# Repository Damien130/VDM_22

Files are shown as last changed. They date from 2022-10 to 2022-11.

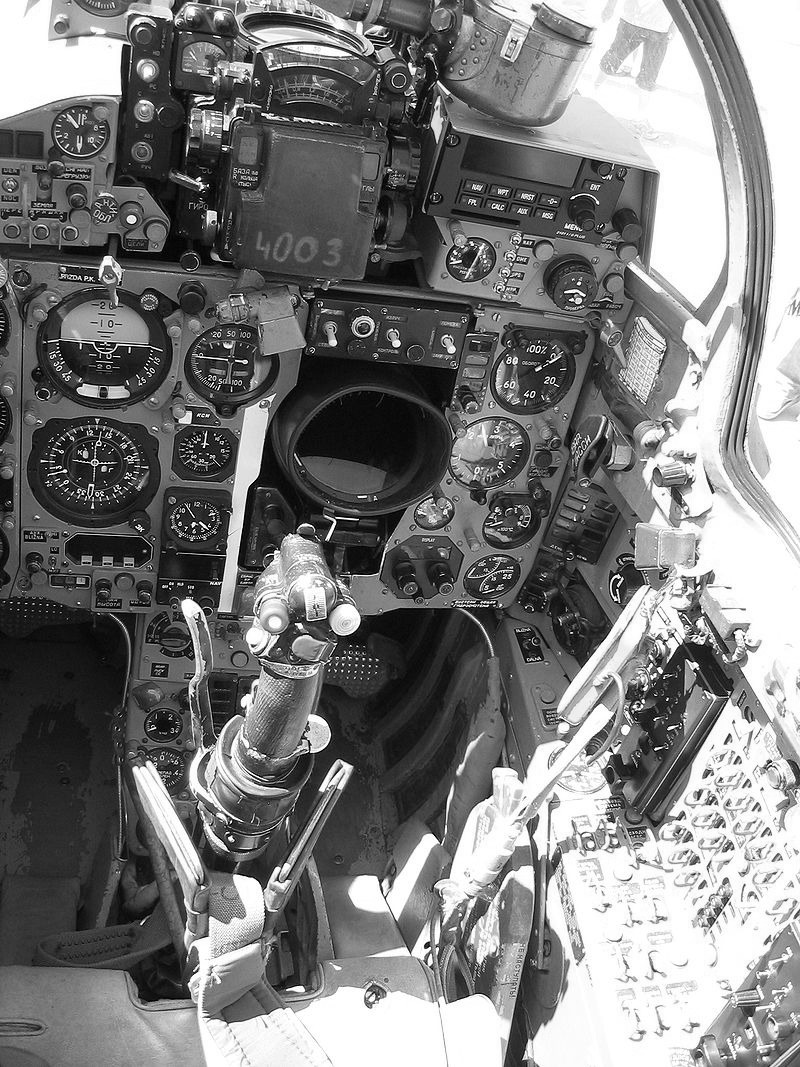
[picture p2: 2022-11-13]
Enclosure Design/image.jpg

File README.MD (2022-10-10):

привет товарищ!

Welcome to your Mikoyan-Gurevich 21, the Pencil.
This will be your jet, you will fly out with Vladimir tomorrow.

What is VDM-22?
The VDM-22 (Vector Drawing Machine - 22) is a vector drawing machine based on the ATMega328P microcontroller. The default machine functions replicates the RP-22 Sapfir radar found on the MiG-21 interceptors. 

Real World Operation
The RP-21/22 Sapfir was an analog radar system developed by the Soviet Union. Used primarily by the MiG-21 Bis, it can detect a fighter sized object from 20 km away flying at the same altitude. The radar antenna scans in a circular motion and emits a characteristic three tone signature on NATO RWRs, earning it the NATO nickname “Spin Scan”. It is capable of operating in three modes – Scan Mode, Chase Mode (locked on) and Fixed Beam (for guiding beam-riding ground attack rockets). 

The interface between the RP-22 and the pilot comes in the form of a circular CRT situated to the lower right side of the MiG-21’s cockpit. The following pictures will depict the two air-to-air operation mode of the radar 

In B-Scope mode, the two horizontal line represents the “lock piper”. When the lock piper is over the bogey (the bird) and the TDC lock button is depressed, the RP-22 will scan the airspace designated by the piper at a high frequency and lock onto any target it sees. 
When used alongside the SRZO-2 IFF interrogator/transponder, the RP-22 is capable of rudimentary IFF operation. When the IFF button is depressed on the radar control panel, the bird will turn into two parallel horizontal lines if the target is friendly and a single line if the target is hostile/unknown. 

When the target is locked following the correct procedure, the RP-22 will enter the “chase mode”. Now instead of a top-down view (a B-scope), the Sapfir will display the C-Scope. The C-Scope displays the azimuth and deviation of the bogey from the centerline of our aircraft, with the two lines on the side representing the distance to target.

When the target is in range for the R3R SARH missile, a red lamp will illuminate with the wording “IN RANGE”. When the target is range, another red lamp “launch” will be lit, giving the pilot launch authorization when he/she presses the missile launch button. 

Gameplay
The gameplay will follow the perspective of a MiG-21/J-7 pilot at the end of GCI guidance. Upon game start, a bogey will appear on the very top edge of the scope (around 30 km). The initial delta V of the two aircrafts will be 800 kts (1481.6kph), which means the player will have about 40 seconds to maneuver the aircraft to lock up the bogey at 15 km. The player will now have to flip on a row of switches – Left Rack Power, Right Rack Power, Left Rack Launch Authorization and Right Rack Launch Authorization to prepare for the engagement. 

Once the player obtains a lock, the interface will be switched to the C-Scope. The bogey has a random chance to start maneuvering and / or lock onto the player’s aircraft. The bogey’s radar status will be reflected by the MiG’s helpful soviet RWR. The RWR, following its real-life model, will consist of one sound unit and 4 LEDS representing the radar emission aspect to own aircraft. When the bogey’s radar is scanning the player’s aircraft, the RWR will beep with the LED flashing in the direction the bogey is coming from. If the bogey obtains a lock / launches a missile, the LED will turn solid, and the beep will turn into a continuous tone/very high frequency beep.  If the bogey obtains a lock on the player, the player must hit the countermeasure dispense button to deploy chaff. For gameplay’s sake, the chaff deployed will have a 100% possibility of confusing the bogey’s targeting system thus ensuring the player’s survival. 

Now if the player manages to evade the bogey’s missile and comes within launch distance (around 7km with both IN RANGE and LAUNCH lamps lit), the player will launch the R3R missile by pressing the missile launch button. If the player launches the missile before the distance closes within 2km, the bogey will be counted as shot down; otherwise, the player will be splashed by a capitalist AIM-9 sidewinder missile. 

Upon finishing one game, the player will press the countermeasures dispense button to start the next round. The next round will multiply the delta V of the player’s aircraft and the bogey’s aircraft by 1.05, and the game will terminate to display score information on the vector scope when delta V reaches 1500 knots.

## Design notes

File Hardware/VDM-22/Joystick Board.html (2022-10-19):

Altium customize

# Board Information Report

Date: | | 10/19/2022
Time: | | 4:58:49 PM
Elapsed Time: | | 00:00:00
Filename: | | Q:\BOP_F14\Hardware\VDM-22\Joystick Board.PcbDoc
Units: | | mmmils

## Contents

Contents

Board Specification

General

Routing

Routing Information

Other

Net Via Size

## Board Specification

General
Board Size | 69mm x 52mm
Components on board | 7

Back to top

## Routing

Routing Information
Routing completion | 100.00%
Connections | -9
Connections routed | -9
Connections remaining | 0

Back to top

## Other

Net Via Size | Count
1.27mm | 39
Total | 39

Back to top

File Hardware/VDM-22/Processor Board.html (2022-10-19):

Altium customize

# Board Information Report

Date: | | 10/19/2022
Time: | | 5:01:15 PM
Elapsed Time: | | 00:00:00
Filename: | | Q:\BOP_F14\Hardware\VDM-22\Processor Board.PcbDoc
Units: | | mmmils

## Contents

Contents

Board Specification

General

Routing

Routing Information

Other

Net Via Size

## Board Specification

General
Board Size | 69.723mm x 95.885mm
Components on board | 48

Back to top

## Routing

Routing Information
Routing completion | 100.00%
Connections | 141
Connections routed | 141
Connections remaining | 0

Back to top

## Other

Net Via Size | Count
1mm | 39
Total | 39

Back to top

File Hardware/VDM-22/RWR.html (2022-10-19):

Altium customize

# Board Information Report

Date: | | 10/19/2022
Time: | | 5:00:46 PM
Elapsed Time: | | 00:00:00
Filename: | | Q:\BOP_F14\Hardware\VDM-22\RWR.PcbDoc
Units: | | mmmils

## Contents

Contents

Board Specification

General

Routing

Routing Information

Other

Net Via Size

## Board Specification

General
Board Size | 29mm x 30mm
Components on board | 9

Back to top

## Routing

Routing Information
Routing completion | 100.00%
Connections | -26
Connections routed | -26
Connections remaining | 0

Back to top

## Other

Net Via Size | Count
1.27mm | 45
Total | 45

Back to top

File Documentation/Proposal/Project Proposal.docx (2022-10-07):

# VDM-22 Sapfir

An RP-22 Sapir Radar Scope implementation for the ATmega 328P

# Overview of Vector Drawing Machine - 22

## Real World Operation

The RP-21/22 Sapfir was an analog radar system developed by the Soviet Union. Used primarily by the MiG-21 Bis, it can detect a fighter sized object from 20 km away flying at the same altitude. The radar antenna scans in a circular motion and emits a characteristic three tone signature on NATO RWRs, earning it the NATO nickname “Spin Scan”. It is capable of operating in three modes – Scan Mode, Chase Mode (locked on) and Fixed Beam (for guiding beam-riding ground attack rockets).

The interface between the RP-22 and the pilot comes in the form of a circular CRT situated to the lower right side of the MiG-21’s cockpit. The following pictures will depict the two air-to-air operation mode of the radar (Fixed Beam for Kh22 is for ground attack only, and will not be implemented in the current iteration):

1. B-Scope (Detection). 2. Chase Mode

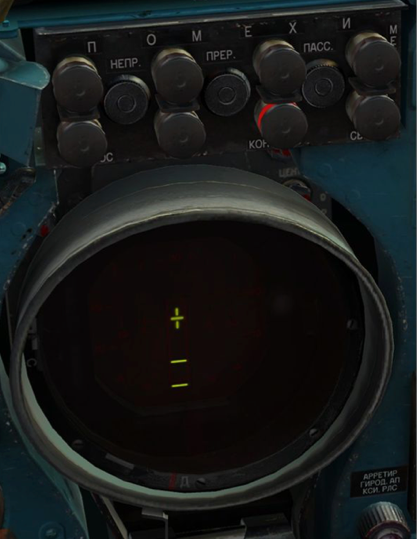
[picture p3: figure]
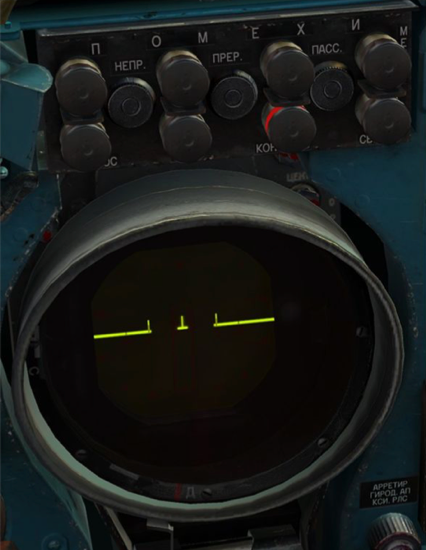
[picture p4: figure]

In B-Scope mode, the two horizontal line represents the “lock piper”. When the lock piper is over the bogey (the bird) and the TDC lock button is depressed, the RP-22 will scan the airspace designated by the piper at a high frequency and lock onto any target it sees.

When used alongside the SRZO-2 IFF interrogator/transponder, the RP-22 is capable of rudimentary IFF operation. When the IFF button is depressed on the radar control panel, the bird will turn into two parallel horizontal lines if the target is friendly and a single line if the target is hostile/unknown.

When the target is locked following the correct procedure, the RP-22 will enter the “chase mode”. Now instead of a top-down view (a B-scope), the Sapfir will display the C-Scope. The C-Scope displays the azimuth and deviation of the bogey from the centerline of our aircraft, with the two lines on the side representing the distance to target.

When the target is in range for the R3R SARH missile, a red lamp will illuminate with the wording “IN RANGE”. When the target is range, another red lamp “launch” will be lit, giving the pilot launch authorization when he/she presses the missile launch button.

## Gameplay

The gameplay will follow the perspective of a MiG-21/J-7 pilot at the end of GCI guidance. Upon game start, a bogey will appear on the very top edge of the scope (around 30 km). The initial delta V of the two aircrafts will be 800 kts (1481.6kph), which means the player will have about 40 seconds to maneuver the aircraft to lock up the bogey at 15 km. The player will now have to flip on a row of switches – Left Rack Power, Right Rack Power, Left Rack Launch Authorization and Right Rack Launch Authorization to prepare for the engagement.

Once the player obtains a lock, the interface will be switched to the C-Scope. The bogey has a random chance to start maneuvering and / or lock onto the player’s aircraft. The bogey’s radar status will be reflected by the MiG’s helpful soviet RWR. The RWR, following its real-life model, will consist of one sound unit and 4 LEDS representing the radar emission aspect to own aircraft. When the bogey’s radar is scanning the player’s aircraft, the RWR will beep with the LED flashing in the direction the bogey is coming from. If the bogey obtains a lock / launches a missile, the LED will turn solid, and the beep will turn into a continuous tone/very high frequency beep. If the bogey obtains a lock on the player, the player must hit the countermeasure dispense button to deploy chaff. For gameplay’s sake, the chaff deployed will have a 100% possibility of confusing the bogey’s targeting system thus ensuring the player’s survival.

Now if the player manages to evade the bogey’s missile and comes within launch distance (around 7km with both IN RANGE and LAUNCH lamps lit), the player will launch the R3R missile by pressing the missile launch button. If the player launches the missile before the distance closes within 2km, the bogey will be counted as shot down; otherwise, the player will be splashed by a capitalist AIM-9 sidewinder missile.

Upon finishing one game, the player will press the countermeasures dispense button to start the next round. The next round will multiply the delta V of the player’s aircraft and the bogey’s aircraft by 1.05, and the game will terminate to display score information on the vector scope when delta V reaches 1500 knots.

# Hardware Description

Revised from the preliminary proposal, the entire game will be powered by one ATMega328P microcontroller. Instead of using the unreliable PWM output of the microcontroller itself, we will use an AD7302 dual 8-bit DAC to complete the DAC operation.

We will then use two pins from the ADC port for joystick input, 2 pins for launch / countermeasures dispense, 1 pin for MASTER ARM (Rail Power), 2 pins for RWR LED control and finally 1 pin for buzzer RWR feedback. Combined we will utilize 14 pins for I/O purposes. The current schematic state and block diagram is included below:

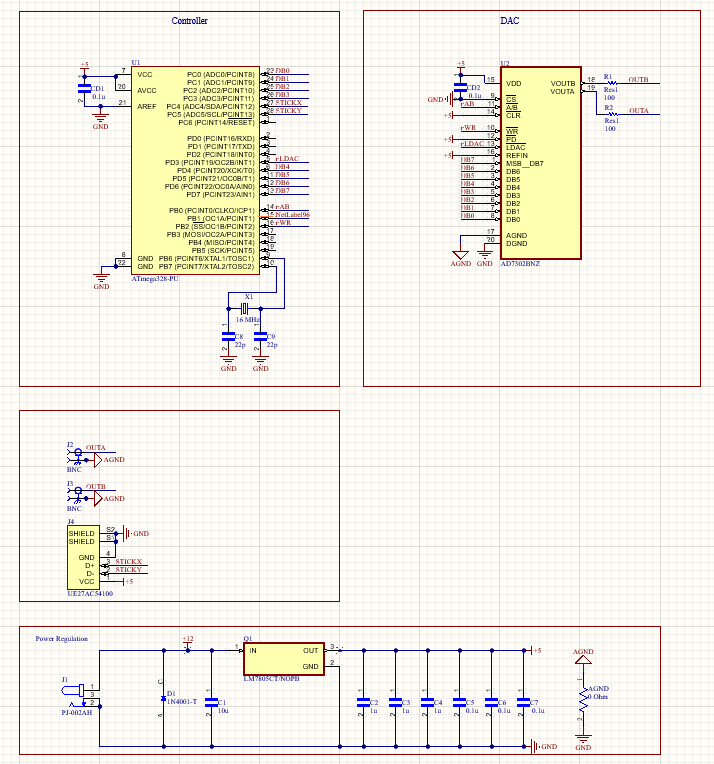
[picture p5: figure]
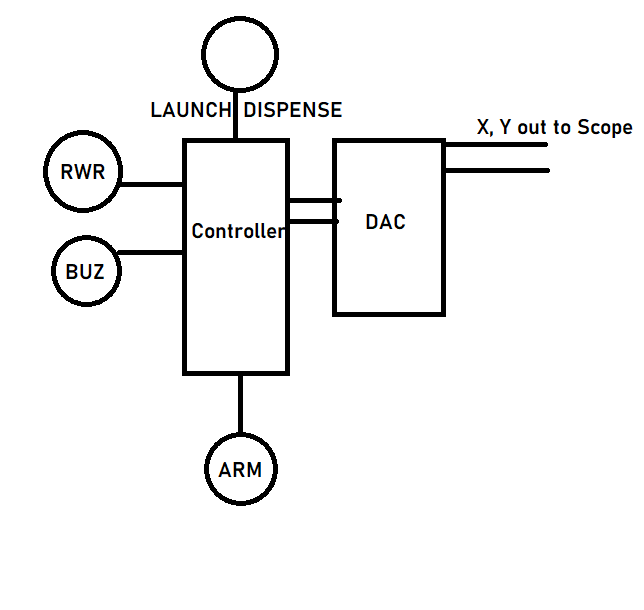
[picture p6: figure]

# Enclosure Design

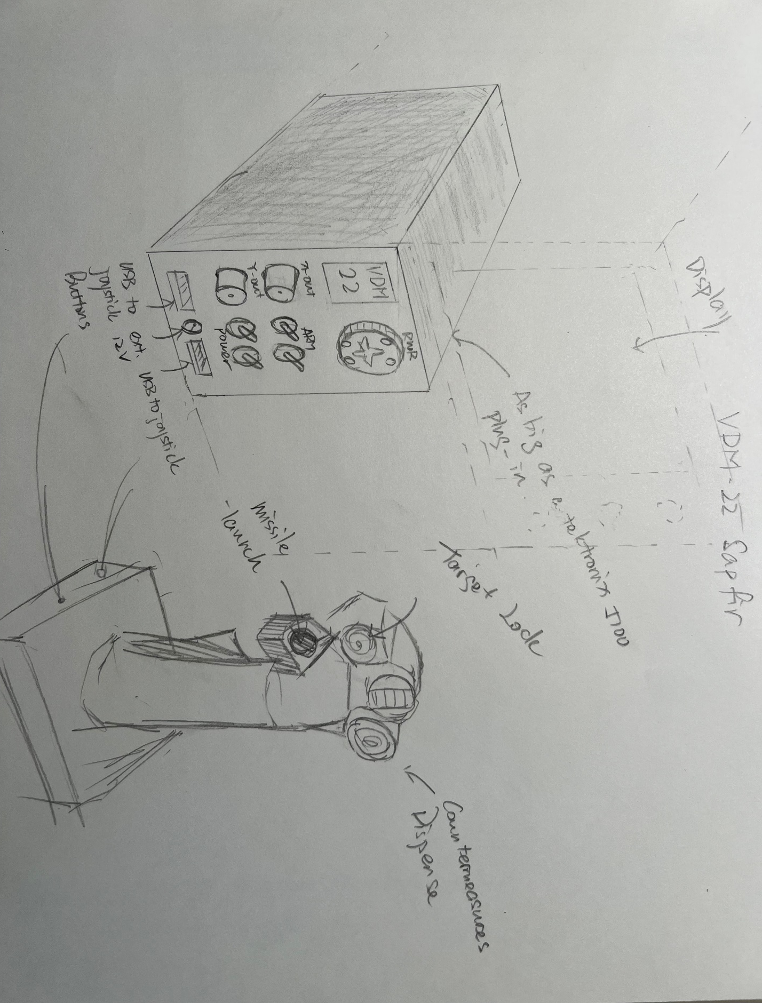
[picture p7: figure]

# Team Roles:

Damien Hu: Hardware/Testing Engineer

Yinhao Qian: Software Engineer

Shaoyu Pei: Enclosure/Testing Engineer

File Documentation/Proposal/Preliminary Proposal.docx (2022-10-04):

Design Project #2 Preliminary Proposal

Grumman F14 Tomcat / MiG-21 Bis Fishbed Radar B-Scope over Oscilloscope Vector Graphics

1. Hardware Introduction

This project will simulate the radar B-scope of the F14 or the MiG-21’s radar B-scope along with RWR sound (radar ping, radar lock, launch warning etc.). Both aircraft utilizes vector graphics to display B scope information on a circular CRT, mounted in the RIO’s seat and lower right side of the cockpit respectively. A demonstration of both scopes is shown below:

F14:

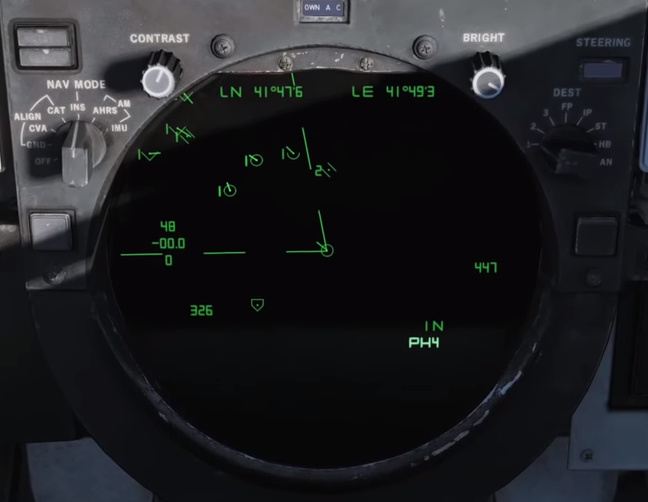
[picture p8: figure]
RIO Nugget - Day 1 AAR - DCS F-14 Tomcat - Mudspike Forums

MiG-21:

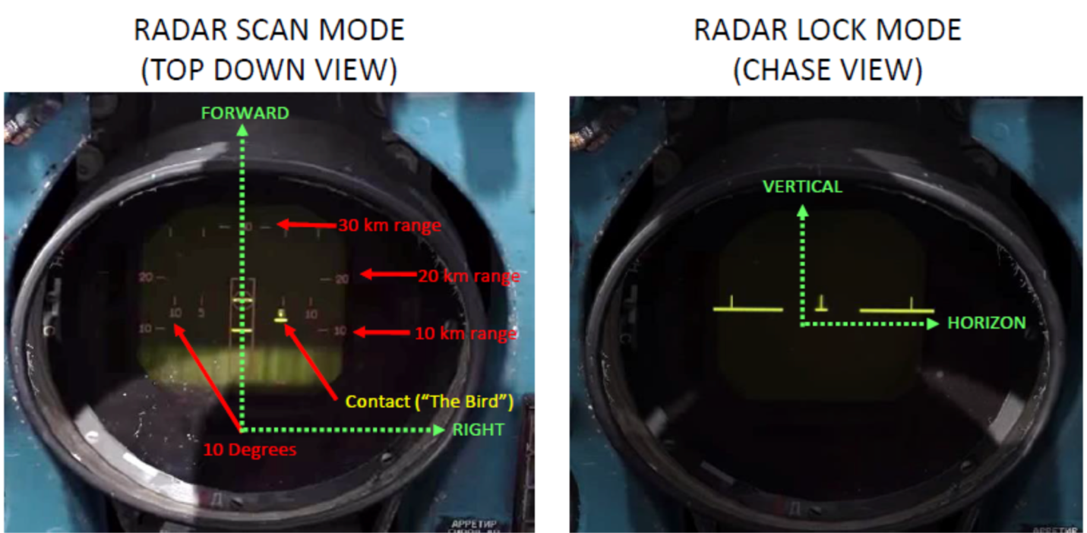
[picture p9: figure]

The goal is to use a combination of an STM328P microcontroller and a TLC7528 dual 8-bit DAC to generate a stereo waveform output, then displaying the generated graphics using X/Y mode on an analog oscilloscope. Depending on available time and/or difficulty, either the F14 (More complex, involves both square/triangle wave and sinusoidal waves) or the MiG-21 (consists primarily of square waves) will be implemented.

As the 8-bit TLC7528 along with the inputs will be taking up most of the available I/O pins on the STM328P, a second STM328P will be used to provide auditory feedback. This co-processor will control the famous Yamaha YM2149 sound chip with a 2-bit input to select between different sound profiles – Bogey Lock, Bogey Launch Warning, missile launch and mute.

2. Gameplay

The inputs will be one joystick, one flip switch for MASTER ARM and one button (or more) for missile launch and other features like countermeasures dispense if time permits.

Upon game start, the player will see the bogey pop up on the radar scope. Depending on the aircraft model the player will either have to “hook” the bogey with the joystick or “maneuver” the aircraft till the piper lines up with the bogey and obtain a lock.

Once a lock is obtained, there’s a random chance the bogey will proceed to lock the player. Based on RWR feedback, the player will have to decide between pressing the attack or going defensive.

When the bogey is within missile range (~50 nm for the Cat’s Phoenix and ~7 nm for the R3R), a visual cue will appear on screen. The player will then press the launch button to launch the missile and destroy the bogey.

If the player fails to launch the missile / gets hit by the enemy launch by not notching before the bogey pushes to within 2nm, the game will end with the player being hit by an R73 or AIM-9M.

The end game score will be displayed on the Oscilloscope via existing vector font library.

Inspiration for this project is taken from my experiences in DCS World and recent acquisition of a free Tektronix 5110 mainframe oscilloscope retired from the ME department.

A demonstration of what the scope can do can be found here:

https://www.youtube.com/watch?v=19jv0HM92kw

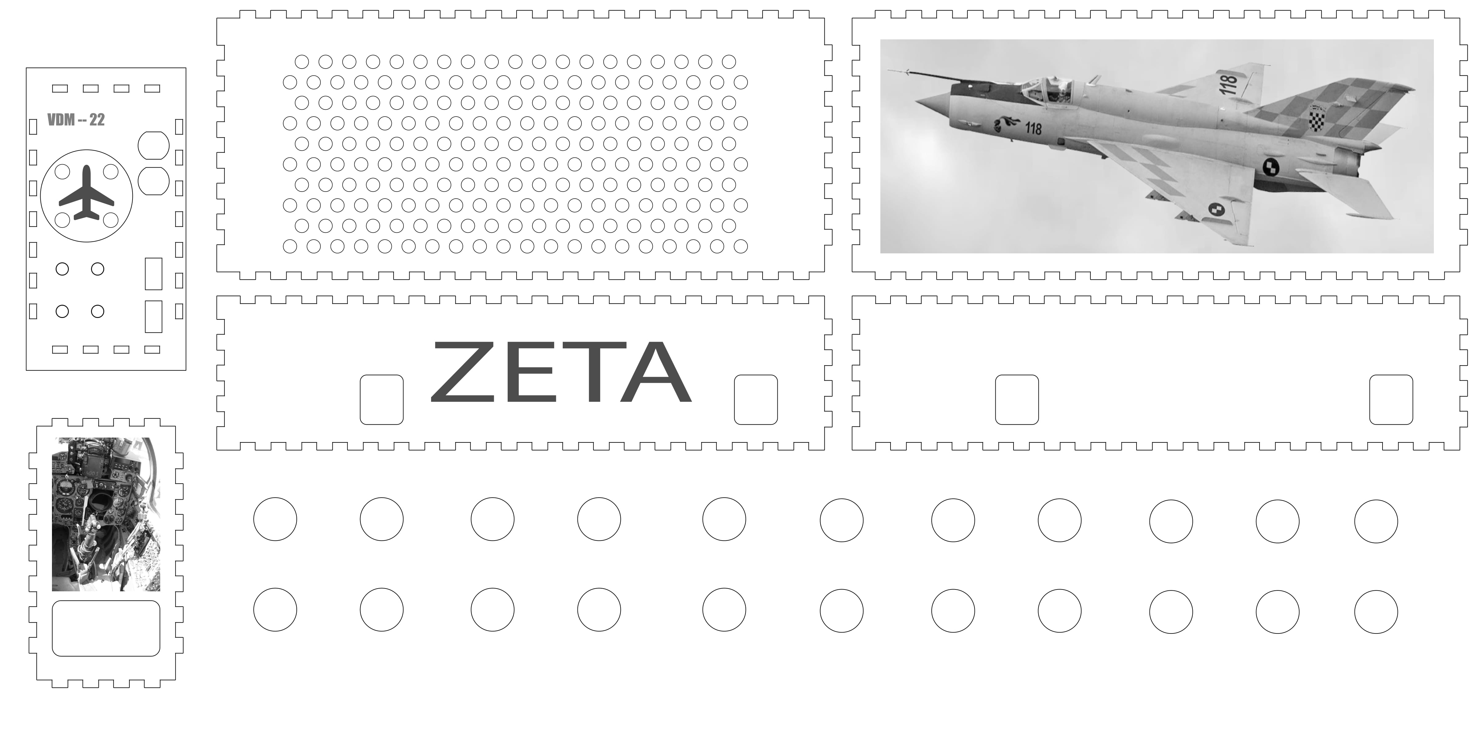
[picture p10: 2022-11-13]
Enclosure Design/VDM22_v2-1.jpg

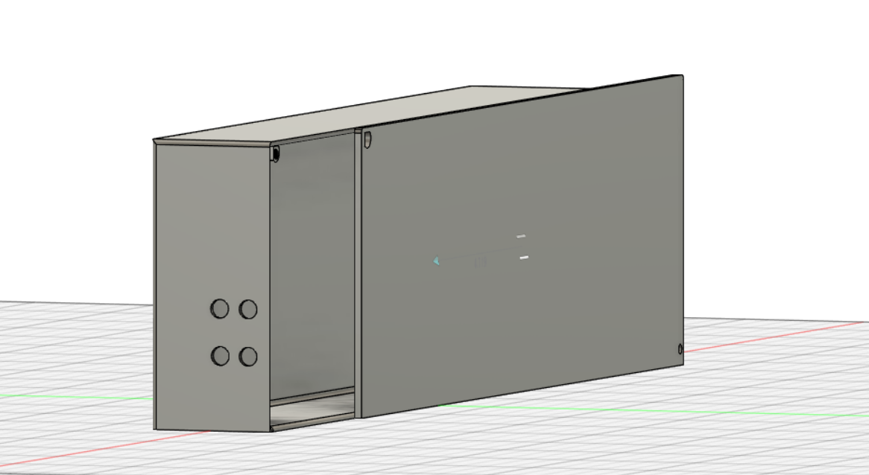
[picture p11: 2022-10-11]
Enclosure Design/A Simple Box/ECE1895HW15_OptionA.png

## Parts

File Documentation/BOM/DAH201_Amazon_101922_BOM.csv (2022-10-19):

Quantity | Link | Description | Pitt User ID | Unit Price | Extended Price USD
2 | Amazon.com: Amazon Basics 23A Alkaline Battery - Pack of 4 : Health & Household | Amazon Basics 23A Alkaline Battery - Pack of 4 | DAH201 | 4.1 | 8.2

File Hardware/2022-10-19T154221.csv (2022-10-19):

Index | Quantity | Part Number | Manufacturer Part Number | Description | Customer Reference | Available | Backorder | Unit Price | Extended Price USD
1 | 5 | 609-10129381-918001BLF-ND | 10129381-918001BLF | CONN HEADER VERT | DAH201 | 5 | 0 | 0.45000 | 2.25
2 | 15 | A121481-ND | 5-146281-2 | CONN HEADER VERT 2POS 2.54MM | DAH201 | 15 | 0 | 0.39100 | 5.87
3 | 3 | 102-4993-ND | SJ1-3555NG-BE | CONN JACK STEREO 3.5MM R/A | dah201 | 3 | 0 | 0.97000 | 2.91
4 | 4 | 609-4711-ND | 69192-406HLF | CONN HEADER VERT 6POS 2.54MM | DAH201 | 4 | 0 | 0.45000 | 1.80
5 | 3 | EG5350CT-ND | TL3305AF160QG | SWITCH TACTILE SPST-NO 50MA 12V | dah201 | 3 | 0 | 0.21000 | 0.63
6 | 3 | 2223-CPI-137-83T-ND | CPI-137-83T | BUZZER PIEZO 5V 13.9MM TH | DAH201 | 3 | 0 | 2.01000 | 6.03
7 | 3 | 102-TBL004V-508-02BE-2GY-ND | TBL004V-508-02BE-2GY | TERMINAL BLOCK, SCREWLESS, 5.08, | dah201 | 3 | 0 | 0.69000 | 2.07
8 | 5 | SW320-ND | GRS-2013A-2000 | SWITCH ROCKER SPDT 16A 125V | DAH201 | 5 | 0 | 1.04000 | 5.20
9 | 5 | A121482-ND | 5-146281-3 | CONN HEADER VERT 3POS 2.54MM | DAH201 | 5 | 0 | 0.60000 | 3.00
10 | 3 | BH23AW-ND | BH23AW | BATT HOLDER A23 1 CELL 6" LEADS | DAH201 | 3 | 0 | 1.87000 | 5.61
11 | 8 | UE27AC54100-ND | UE27AC54100 | CONN RCPT USB2.0 TYPEA 4POS R/A | DAH201 | 8 | 0 | 0.67000 | 5.36
12 | 10 | 399-4220-ND | C317C220J2G5TA | CAP CER 22PF 200V NP0 RADIAL | DAH201 | 10 | 0 | 0.12700 | 1.27
13 | 10 | 0.0QBK-ND | ZOR-25-B-52-0R | RES 0 OHM JUMPER 1/4W AXIAL | DAH201 | 10 | 0 | 0.13100 | 1.31
14 | 10 | S1KHCT-ND | CFM12JT1K00 | RES 1K OHM 5% 1/2W AXIAL | DAH201 | 10 | 0 | 0.06700 | 0.67
15 | 10 | CF12JT10K0CT-ND | CF12JT10K0 | RES 10K OHM 5% 1/2W AXIAL |  | 10 | 0 | 0.07200 | 0.72
16 | 2 | SAM10918-ND | BNC7T-J-P-HN-RA-BH1 | CONN BNC JACK R/A 75 OHM PCB | DAH201 | 2 | 0 | 20.83000 | 41.66
17 | 16 | 516-HLMP-C423-ND | HLMP-C423 | LED ORANGE CLEAR T-1 3/4 T/H | DAH201 | 16 | 0 | 0.48100 | 7.70
18 | 10 | CF12JT150RCT-ND | CF12JT150R | RES 150 OHM 5% 1/2W AXIAL | DAH201 | 10 | 0 | 0.07200 | 0.72
19 | 2 | 1568-1526-ND | COM-09032 | JOYSTICK 10K OHM 2 AXIS TH | DAH201 | 2 | 0 | 4.50000 | 9.00
20 | 10 | 445-180543-1-ND | FA18X7R1E105KRU06 | CAP CER 1UF 25V X7R RADIAL | DAH201 | 10 | 0 | 0.25700 | 2.57
21 | 4 | CWI278-ND | GPB553B2L01BU | SWITCH PUSHBUTTON SPST 10A 14V | DAH201 | 4 | 0 | 9.55000 | 38.20
22 | 4 | 360-2827-ND | M2011SS1W01 | SWITCH TOGGLE SPST 6A 125V | DAH201 | 4 | 0 | 4.73000 | 18.92

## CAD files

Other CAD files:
Enclosure Design/A Simple Box/ECE1895HW15_OptionA.f3d

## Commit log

2022-10-05 initialize Altium Project
    [Processor Board.SchDoc, VDM-22.PrjPcb]
2022-10-05 Modified Schematic Size
    [Processor Board.SchDoc]
2022-10-05 Test Altium Git Intergration
    [Processor Board.SchDoc]
2022-10-06 added VDM-3 schematic
2022-10-06 Added Power Block, DAC and MicroController
    [Processor Board.SchDoc]
2022-10-06 Added Connectors and Updated PCB
    [Processor Board.PcbDoc, Processor Board.SchDoc]
2022-10-07 Block Diagram, BOM
    [DAH201_DigiKey_100722_BOM.csv]
2022-10-07 added enclosure design
2022-10-11 Schematic Final Revision 1
    [Processor Board.PcbDoc, Processor Board.SchDoc]
2022-10-11 finish HW15
    Option A: design a simple box
    [ECE1895HW15_OptionA.f3d]
2022-10-15 Finalized Schematic
    [Processor Board.PcbDoc, Processor Board.SchDoc]
2022-10-17 Bottom Layer routed
    [Processor Board.PcbDoc, Processor Board.SchDoc]
2022-10-17 Fixed terminal block connection, finished PCB routing.
    [Processor Board.PcbDoc, Processor Board.SchDoc]
2022-10-18 Board revision 2
    [Processor Board.PcbDoc]
2022-10-19 Finalized Board Release Version 1.0 Added PCB PDF File
    [Processor Board.SchDoc, VDM-22.PrjPcb]
2022-10-19 Finalized DRC
    [VDM-22.PrjPcb]
2022-10-19 Fix Rev 1.1
    [Processor Board.SchDoc]
2022-10-19 Added joystick board
    [Joystick Board.PcbDoc, Joystick Board.SchDoc, VDM-22.PrjPcb]
2022-10-19 Added RWR Board
    [Joystick Board.PcbDoc, RWR.PcbDoc, RWR.SchDoc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]
2022-10-19 Final Version 1.3
    [Joystick Board.PcbDoc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]
2022-10-19 Hardware Section Complete
    [VDM-22.PrjPcb]
2022-11-13 final enclosure files
